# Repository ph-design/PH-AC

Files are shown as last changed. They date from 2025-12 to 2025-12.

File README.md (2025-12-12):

English Version | [中文版](README-zh_CN.md)

---

# PH-AC Release 3.0

PH-AC is an open-source 7-button + 2-encoder arcade controller based on RP2040, optimized for rhythm/music games. Release 3.0 preserves the 7-button + 2-encoder layout while adding 3D/PCB/CAD resources, customizable RGB key lighting, and additional GPIO breakouts for easier DIY mods and mass production.

## Project Structure
```
PH60 Rev.2
├── Case_Model_Rev2                 # Case 3D model files
├── LICENSE                         # Project license
├── PCB_Model_Rev2                  # PCB 3D model files
├── PCB_Rev2                        # PCB design files
├── Plate                           # Plate files
├── Preview                         # Preview images
├── Production                      # Production files
├── README-zh_CN.md                 # Chinese README
└── README.md                       # English README
```

Rev3 is mainly aimed at organizing 3D, PCB and production resources and pairs with our new firmware PHAC_Firmware:

https://github.com/ph-design/phac_firmware

Detailed hardware descriptions, assembly instructions, firmware configuration, and maintenance recommendations have been migrated to the official wiki:

https://wiki.phdesign.cc/PHAC/

The hardware project is mature and will not receive further updates.

## Preview

<p align="center">
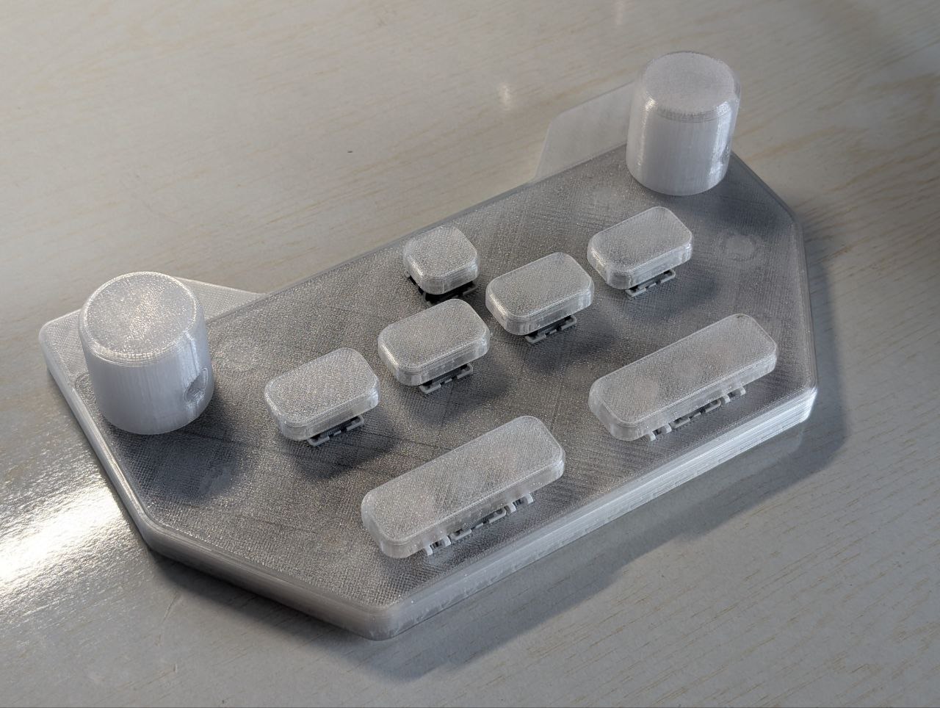
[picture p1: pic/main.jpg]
PH-AC front view
	
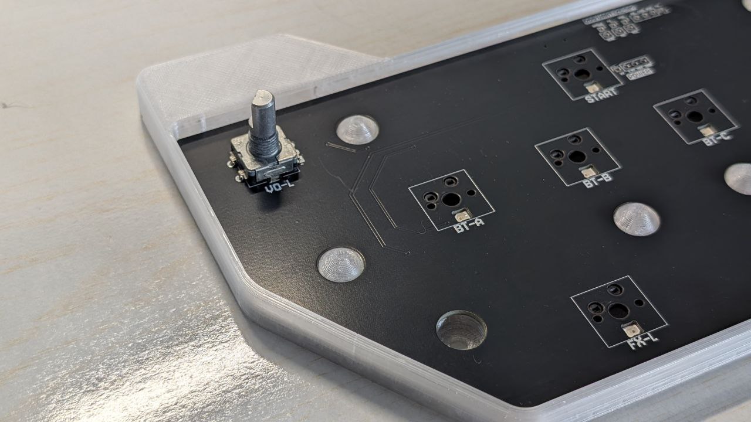
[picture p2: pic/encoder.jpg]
PH-AC PCB
	
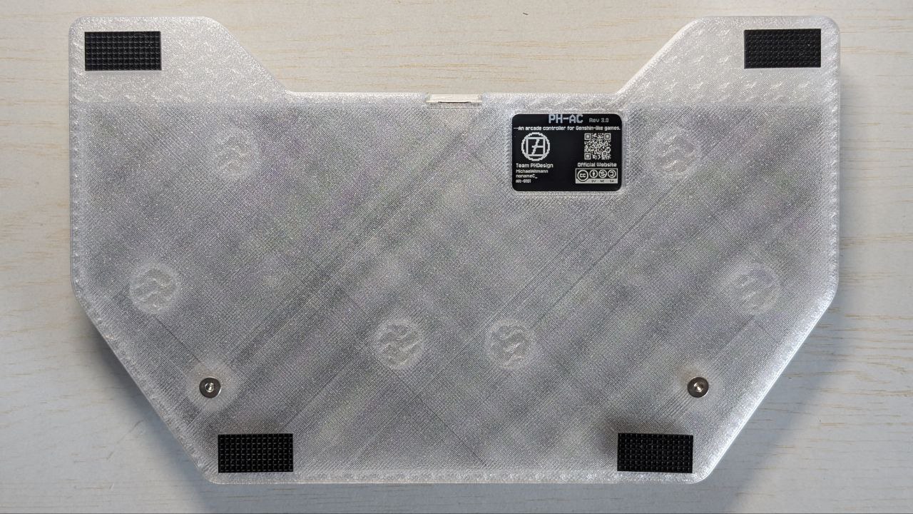
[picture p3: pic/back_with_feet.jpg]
PH-AC case
	
</p>

---

## Release Highlights

- **Rev3 Hardware**: Added per-key RGB lighting and external GPIO breakouts so you can add almost anything you want.
- **Production Files & BOM**: Files prepared for JLCPCB; generate other formats from the KiCad sources if needed.
- **Firmware Evolution**: Rev3 uses our own [PHAC_firmware](https://github.com/ph-design/phac_firmware), which is more suited for arcade-style games than QMK, though older QMK-based firmware remains usable.

## Maintenance Notes

- Avoid applying excessive force to the encoders to prolong their life.
- The top cover fits 4.5mm low-profile encoders; standard-height encoders may interfere with the pins.
- The PCB does not include additional encoder debouncing circuitry; we recommend using high-quality PEC11L encoders and light lubrication.
- If encoder bounce or backdrive occurs, apply a small drop of 400cs silicone oil to the bottom and repeatedly press/rotate the knob to distribute the lubricant.

## License & Community

- License: Creative Commons BY-NC-SA 4.0.
- Documentation & support: https://wiki.phdesign.cc/PHAC/

Thanks to everyone who contributed, tested, and provided feedback — this was our debut project. This is only the beginning: we look forward to seeing what you create, modify, or remix from here. Inject your ideas, share your builds, and help the project live on through community creativity.

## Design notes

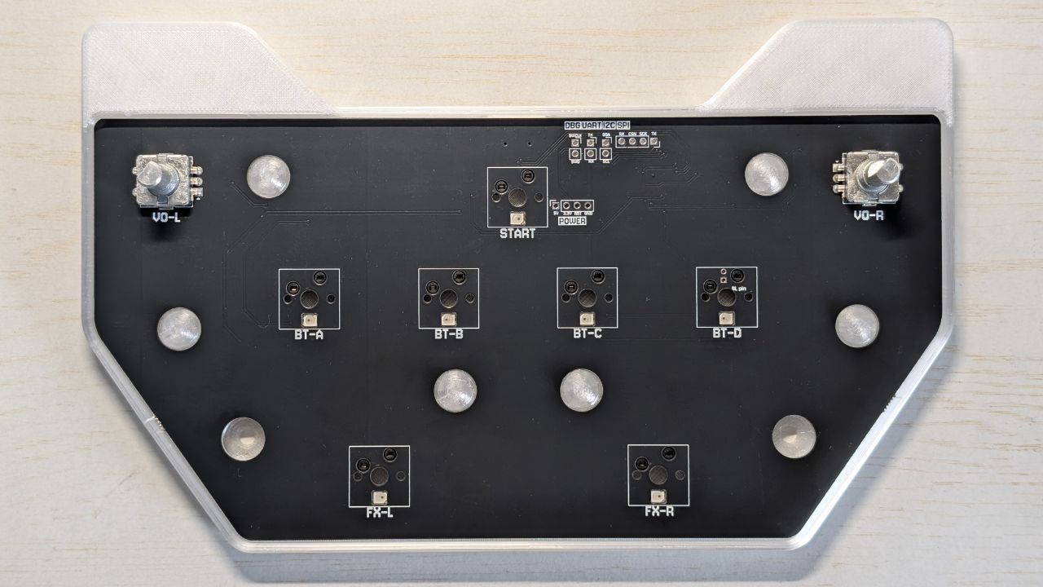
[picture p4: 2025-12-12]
pic/pcb.jpg

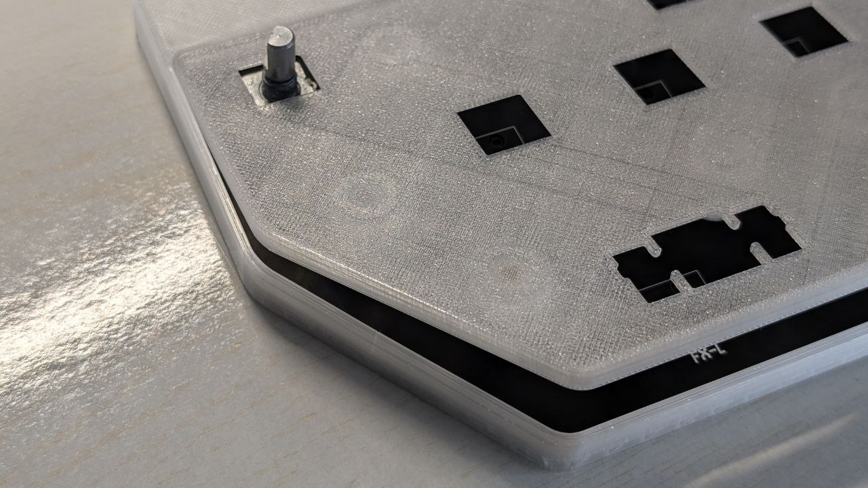
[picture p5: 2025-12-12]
pic/case.jpg

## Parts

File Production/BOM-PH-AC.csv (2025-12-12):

Comment | Designator | Footprint | LCSC | Quantity
1K | R0,R10,R11,R12,R16,R5,R6,R7,R8,R9 | R_0402_1005Metric | C11702 | 10
2u2 | C10,C14,C9 | C_0402_1005Metric | C12530 | 3
Pec11L | VO1,VO2 | RotaryEncoder_Alps_EC11E-Switch_Vertical_H20mm | C143799 | 2
10n | C0,C16,C19,C20 | C_0402_1005Metric | C15195 | 4
100n | C1,C15,C2,C3,C4,C5,C6,C7,C8 | C_0402_1005Metric | C1525 | 9
20p | C17,C18 | C_0402_1005Metric | C1554 | 2
USB_C_Receptacle_USB2.0_16P | J1 | USB_C_Receptacle_GCT_USB4110 | C165948 | 1
RP2040 | U1 | QFN-56-1EP_7x7mm_P0.4mm_EP3.2x3.2mm | C2040 | 1
5K1 | R14,R15 | R_0402_1005Metric | C25905 | 2
SK6812MINI-E | LED0,LED1,LED2,LED3,LED4,LED5,LED6 | LED_6028R | C5149201 | 7
1u | C12,C13 | C_0402_1005Metric | C52923 | 2
XC6206PxxxMR | U0 | SOT-23-3 | C5446 | 1
W25Q32JVSS | U3 | SOIC-8_5.3x5.3mm_P1.27mm | C82344 | 1
X322512MSB4SI | Y1 | Crystal_SMD_3225-4Pin_3.2x2.5mm | C9002 | 1
Conn_01x02_Socket | J0 | PinSocket_1x02_P2.54mm_Vertical |  | 1
SW_Push | SW1 | SW_Hotswap_Kailh_MX_1.50u |  | 1
Conn_01x02_Socket | J2 | PinSocket_1x02_P2.54mm_Vertical |  | 1
SW_Push | SW0 | SW_Hotswap_Kailh_MX_1.00u |  | 1
SW_Push | SW4 | SW_Hotswap_Kailh_MX_1.50u |  | 1
SW_Push | SW2 | SW_Hotswap_Kailh_MX_1.50u |  | 1
SW_Push | SW5 | SW_Hotswap_Kailh_MX_2.25u |  | 1
Conn_01x04_Socket | J3 | PinSocket_1x04_P2.54mm_Vertical |  | 1
SW_Push | SW3 | SW_Hotswap_Kailh_MX_1.50u |  | 1
SW_Push | SW6 | SW_Hotswap_Kailh_MX_2.25u |  | 1
Conn_01x02_Socket | J4 | PinSocket_1x02_P2.54mm_Vertical |  | 1
Conn_01x04_Socket | J5 | PinSocket_1x04_P2.54mm_Vertical |  | 1

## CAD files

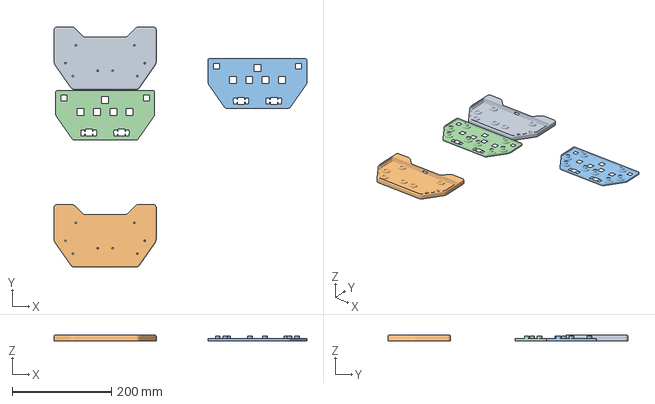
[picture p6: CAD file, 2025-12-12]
3D _Printing/[slicer_file]case_for_bambulab_devices.3mf
510.4 x 484.6 x 12.2 mm
Bottom_Panel x 2
Upper_Panel x 2

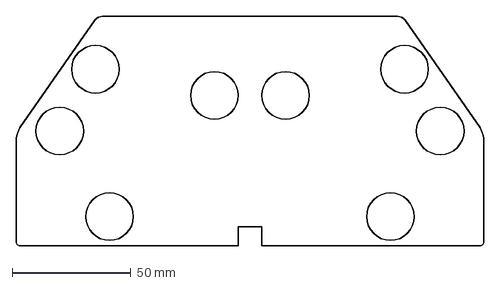
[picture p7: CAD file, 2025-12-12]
Outfit/sound3.DXF
196.4 x 96.5 mm

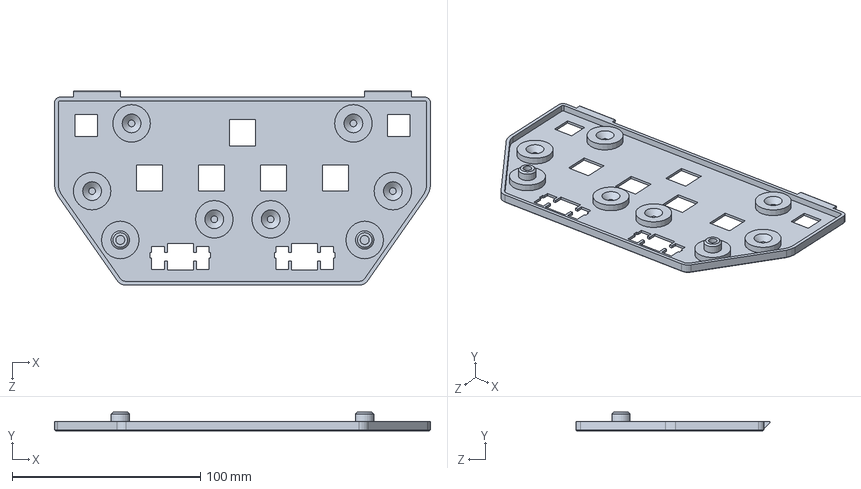
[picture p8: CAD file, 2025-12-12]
Outfit_Rev2/Upper_Panel.SLDPRT
200.0 x 10.0 x 103.3 mm

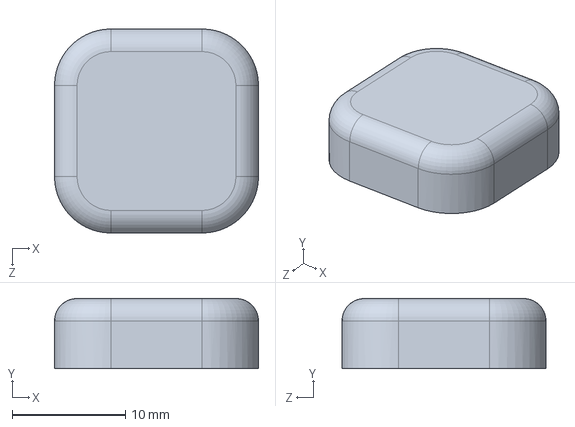
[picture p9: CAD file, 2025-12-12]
Part_Model/Keycap_1u.SLDPRT
18.0 x 6.20 x 18.0 mm

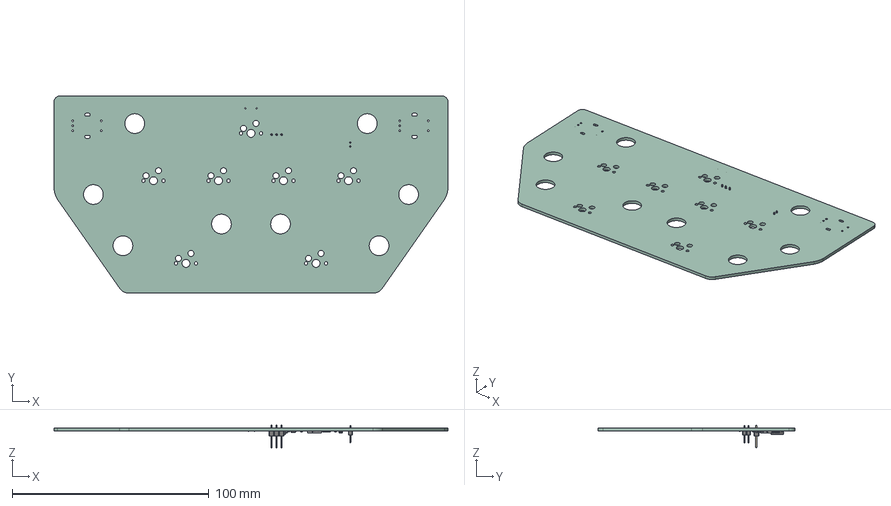
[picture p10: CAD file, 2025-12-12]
PCB_Model/PH-AC.step
200.0 x 100.0 x 11.5 mm
C_0402_1005Metric x 17
SOT_223
R_0402_1005Metric x 7
Crystal_SMD_3225-4Pin_3.2x2.5mm
QFN_56_1EP_7x7mm_P04mm_EP32x32mm
R_0603_1608Metric x 2
LED_1206_3216Metric
PinHeader_1x02_P200mm_Vertical
PinHeader_1x03_P254mm_Vertical
PH-AC_PCB

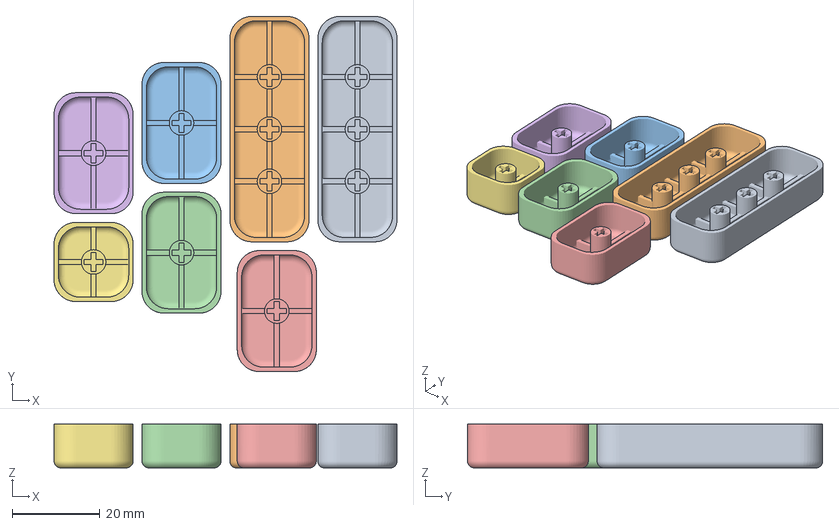
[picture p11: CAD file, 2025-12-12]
3D _Printing/[slicer_file]keycap_for_bambulab_devices.3mf
78.2 x 81.0 x 10.0 mm
Keycap_2.75u x 2
Keycap_1.5u x 4
Keycap_1u

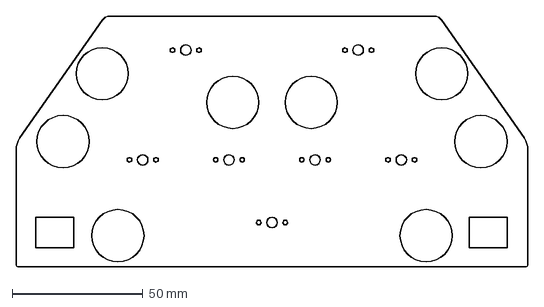
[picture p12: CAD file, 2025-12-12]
Outfit/sound2.DXF
196.0 x 96.1 mm

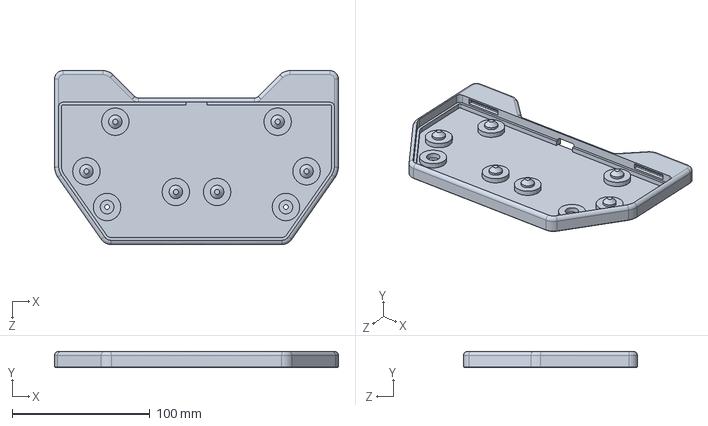
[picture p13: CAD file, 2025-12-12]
Outfit_Rev2/Bottom_Panel.SLDPRT
206.4 x 11.8 x 126.4 mm

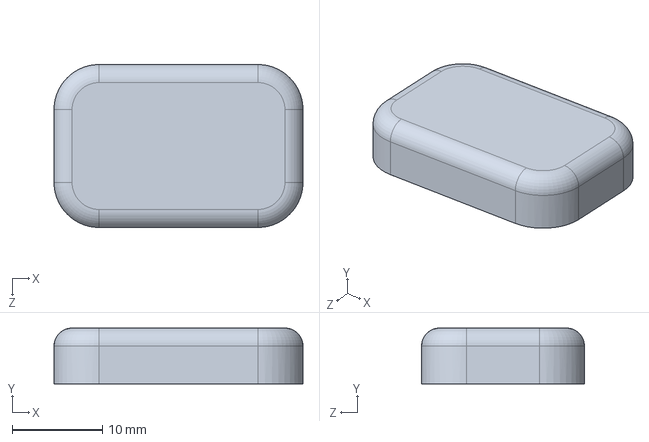
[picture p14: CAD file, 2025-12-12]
Part_Model/Keycap_1.5u.SLDPRT
27.6 x 6.20 x 18.0 mm

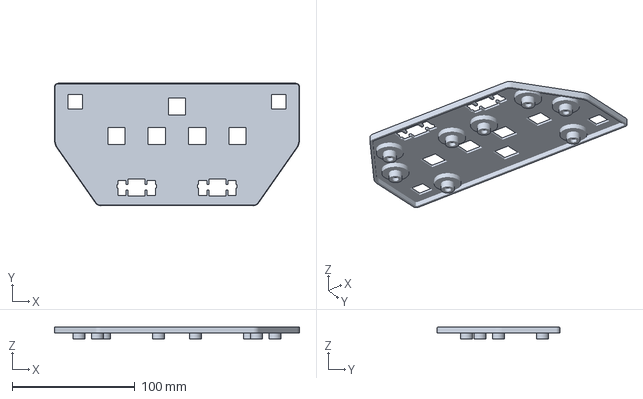
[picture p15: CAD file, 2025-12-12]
3D _Printing/case_upper.3mf
200.0 x 100.0 x 10.0 mm

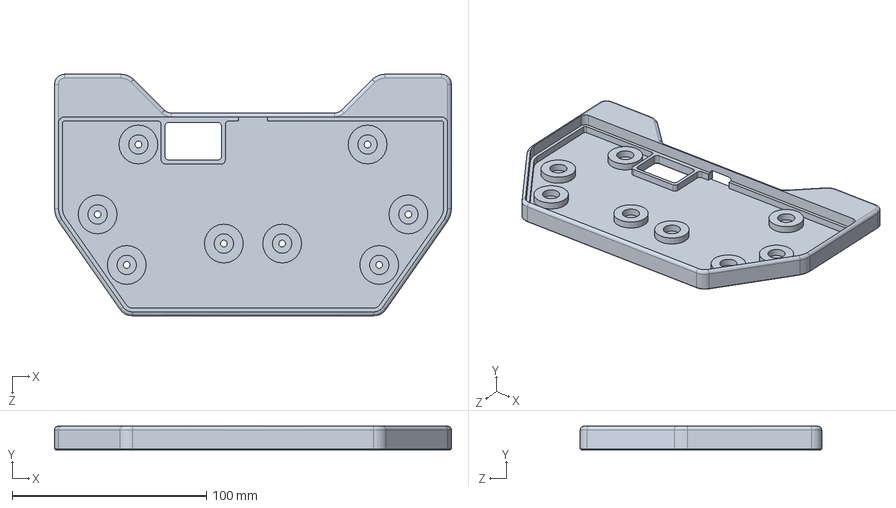
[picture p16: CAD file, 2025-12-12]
Outfit/Bottom_Panel.SLDPRT
204.4 x 12.2 x 124.4 mm

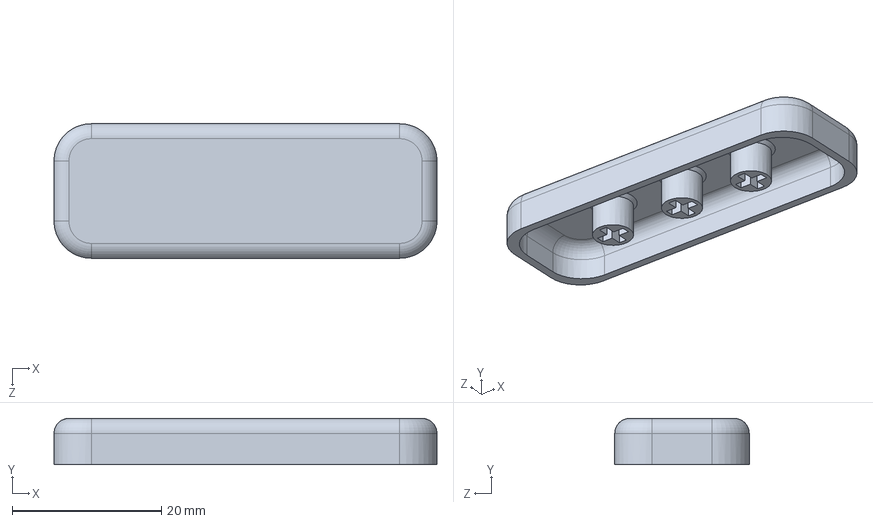
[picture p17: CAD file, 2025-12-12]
Part_Model/Keycap_2.75u.SLDPRT
51.4 x 6.20 x 18.0 mm

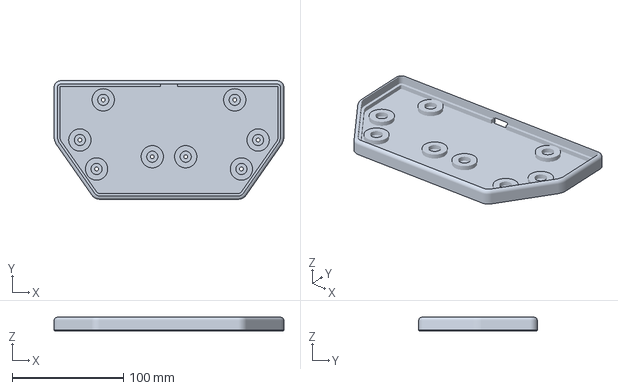
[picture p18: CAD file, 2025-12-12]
3D _Printing/case_bottom.3mf
206.4 x 106.4 x 12.2 mm

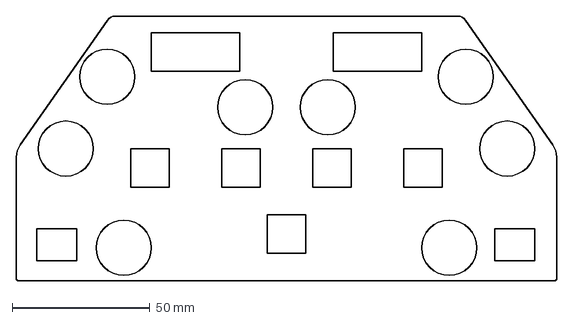
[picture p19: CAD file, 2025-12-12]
Outfit/sound1.DXF
196.0 x 96.1 mm

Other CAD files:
Outfit/Upper_Panel.SLDPRT
3D _Printing/keycap_1.5u.3mf
3D _Printing/keycap_1u.3mf
3D _Printing/keycap_2.75u.3mf

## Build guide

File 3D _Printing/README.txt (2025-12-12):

Printing Guide

打印指南
===========
Slicer files are made with Bambu Studio for Bambulab devices. Case can be printed in X series, P series and A1. Keycaps can be printed in all the devices.
For non-Bambulab devices, create a new project and drag all the single .3mf files into the slicer software. Maintaining 0.2mm layer height and 1 skirt.

切片文件使用Bambu Studio生成，仅适用于拓竹机器。外壳可以使用X1，P1和A1打印，键帽可以使用所有机器打印。
如果您使用非拓竹机器，打开切片软件新建项目，将所有的模型文件拖入项目，保持0.2mm层高的的默认工艺即可打印。添加一圈裙边可以有效改善首层瑕疵。
===========
